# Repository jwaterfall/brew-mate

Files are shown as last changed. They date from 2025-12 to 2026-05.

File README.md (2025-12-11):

# BrewMate

BrewMate is my personal take on a compact coffee scale, derived from [WeighMyBru](https://github.com/031devstudios/weighmybru2). This isn't meant to be a replacement for WeighMyBru—it's just something I designed for myself to suit my preferences, and I'm sharing it in case anyone else wants it too.

Even though the 3D models and code for BrewMate were written from scratch, the project is fundamentally derived from WeighMyBru. I wanted to make the scale more compact and redesign both the scale and web user interfaces to fit my preferences.

BrewMate features a compact form factor of 80×80×18mm. I'm redesigning the scale UI to have a more informative main screen with battery status, Bluetooth, and WiFi status indicators. The project also includes extra hardware modifications to support battery charging detection (VBUS voltage detection using a voltage divider) and battery disconnect detection (3rd switch pin).

## Software Status

⚠️ **Important**: The BrewMate software is currently a work in progress (WIP) and is not ready for use. However, the compact case and alternative hardware can be used with the [WeighMyBru software](https://github.com/031devstudios/weighmybru2).

## Hardware

- ESP32-based microcontroller
  - XIAO ESP32C6
- HX711 load cell amplifier
- SSD1306 OLED display (128x32)
- TTP223 touch sensors
- 500g load cell
- 3.7V 1000mAh battery

## Hardware Differences from WeighMyBru

To fit my more compact case design, some component modifications are needed compared to the standard WeighMyBru BOM. The following table details the components that fit in this compact case:

| Component | Differences | Image |
| --- | --- | --- |
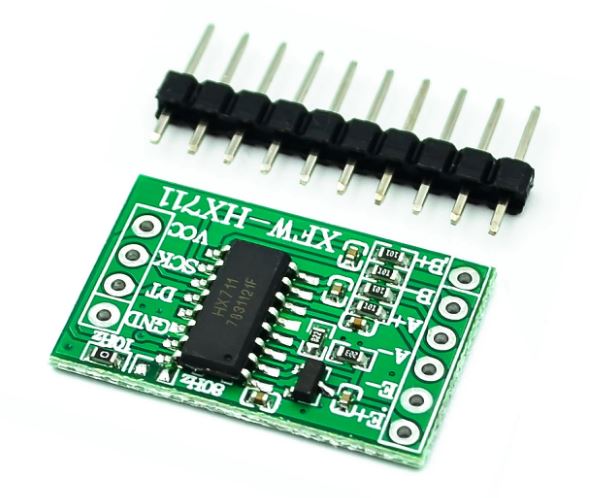
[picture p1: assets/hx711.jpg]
HX711 Compact
| **HX711 Load Cell Amplifier** | Uses the compact version without screw holes (instead of the large version with screw holes). Required to fit within the smaller enclosure. |  |
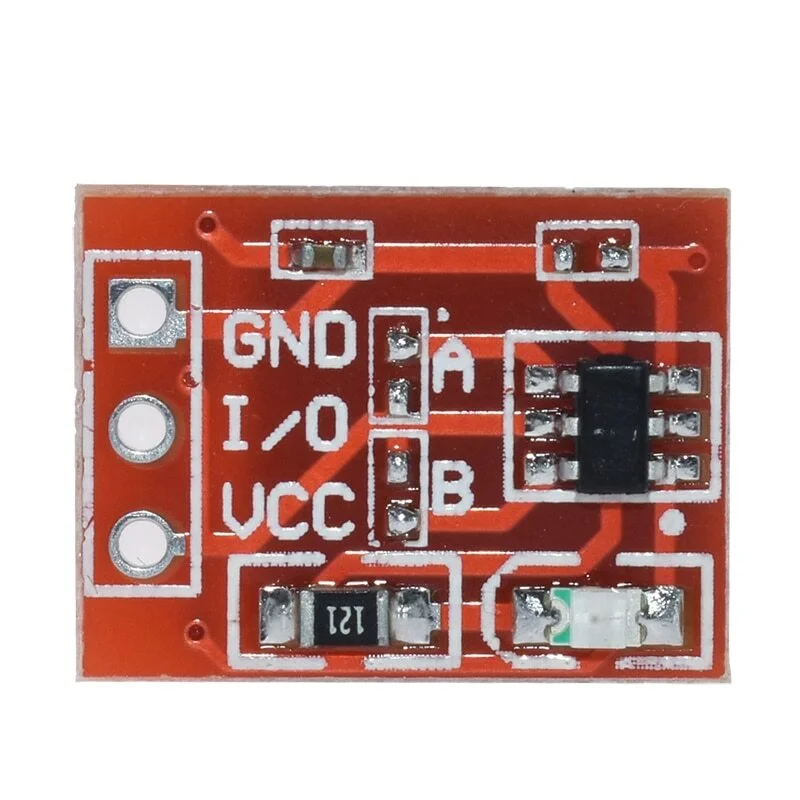
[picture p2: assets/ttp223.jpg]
TTP223 Compact
| **TTP223 Touch Sensors** | Uses compact version with red PCB (instead of standard size). Necessary for the reduced space. |  |
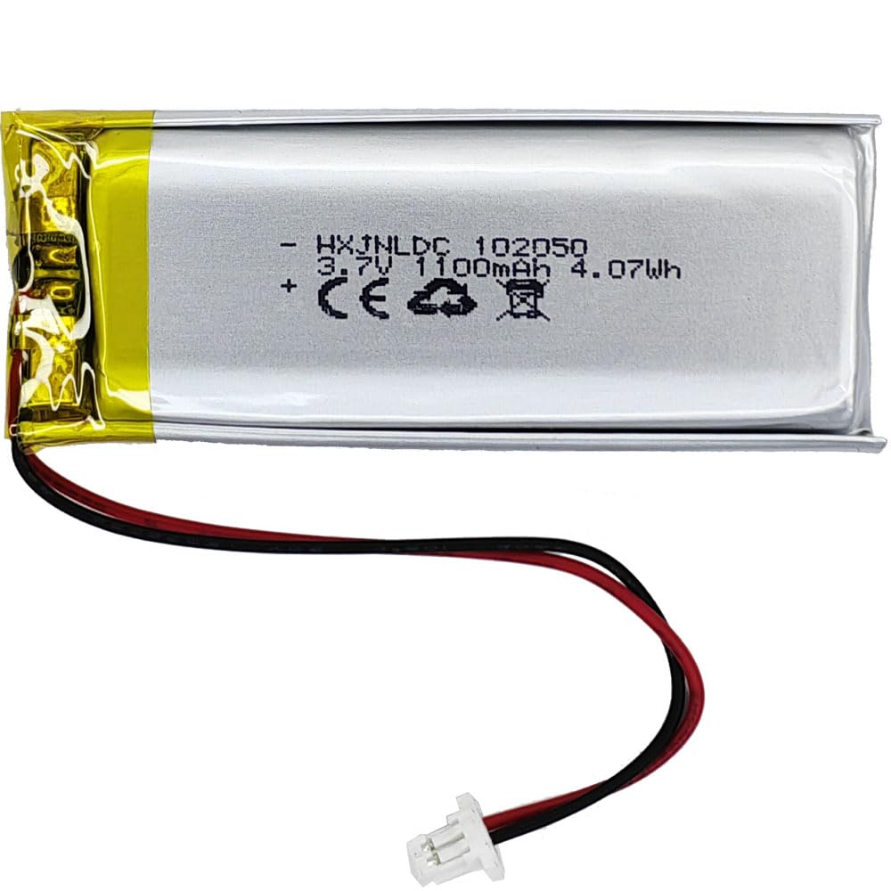
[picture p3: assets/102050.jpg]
102050 Battery
| **Battery** | Uses 102050 battery (10mm × 20mm × 50mm) instead of various sizes. Battery sizing is less forgiving due to the small enclosure. |  |
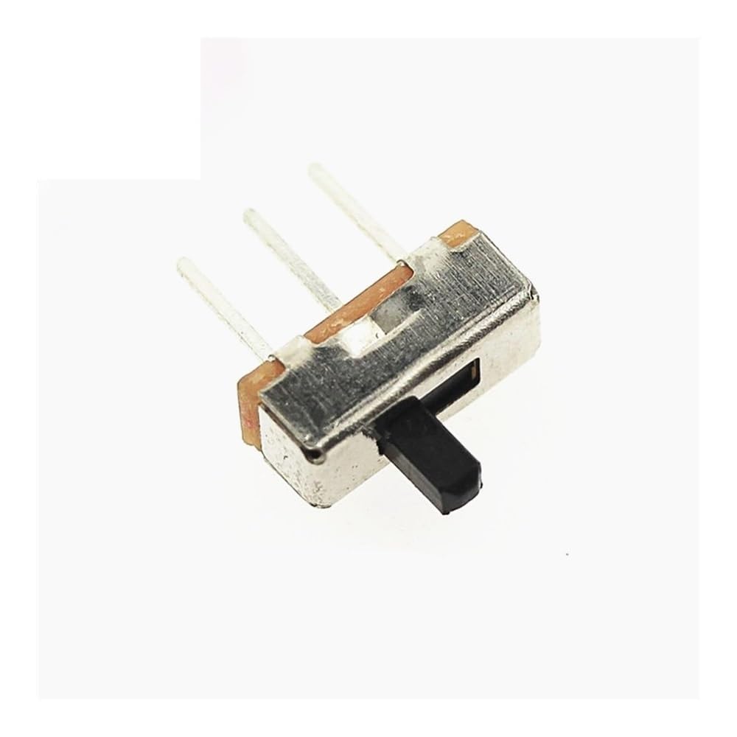
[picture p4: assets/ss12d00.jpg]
Switch
| **Switch** | Uses 4mm stem switch (optional, instead of 5mm stem). A 5mm switch will work but will stick out further and can be cut to length if needed. |  |
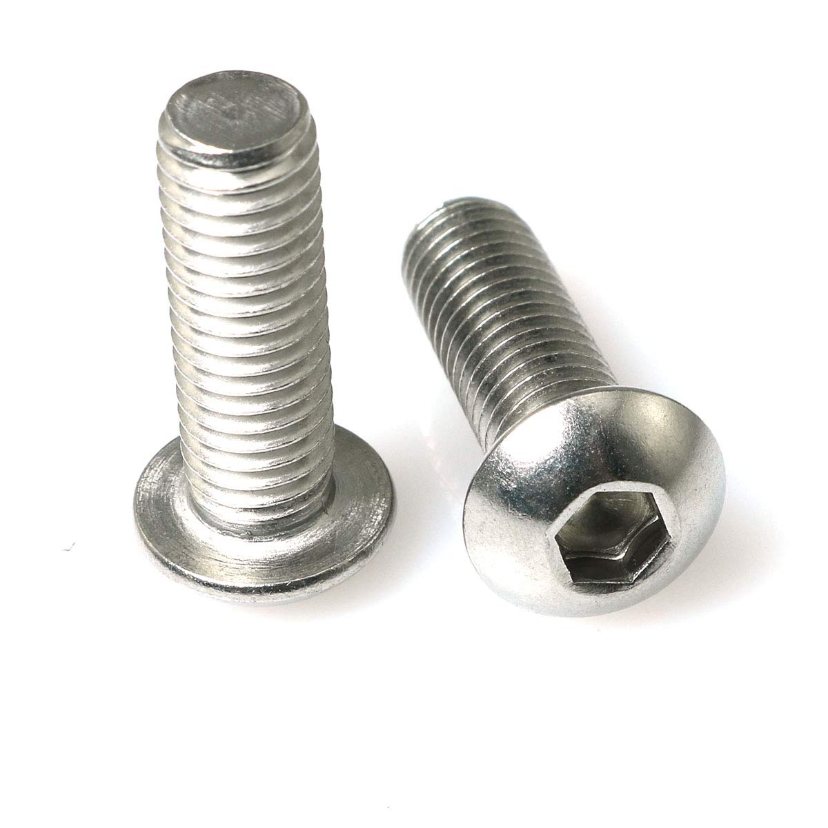
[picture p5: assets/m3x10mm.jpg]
Load Cell Screws
| **Load Cell Screws** | Uses 4× M3x10mm button head screws (instead of M3x12mm). Required for the more compact case design. |  |

## Features

- Flow rate calculation
- Battery level monitoring with USB charging detection
- Compact form factor
- WiFi Access Point mode for initial setup
- WiFi client mode to connect to your home network
- Web-based user interface
- Real-time weight and battery status via web API

## WiFi Web Interface

The scale includes a WiFi Access Point mode for initial setup. When powered on, the scale creates a WiFi network named "BrewMate" (password: `brewmate123`) that allows you to configure the device and connect it to your home WiFi network.

### Setup

1. **Build the web UI:**

   ```bash
   cd web
   pnpm install
   pnpm build
   ```

2. **Upload web files to LittleFS:**

   ```bash
   pio run -t uploadfs
   ```

3. **Upload the firmware:**

   ```bash
   pio run -t upload
   ```

4. **Initial Setup:**

   - Connect your device to the "BrewMate" WiFi network
   - Open a browser and navigate to `http://192.168.4.1`
   - Configure the scale to connect to your home WiFi network
   - Once connected, the scale will switch to WiFi client mode and can be accessed via your local network

5. **Using the scale:**
   - After initial setup, access the web interface via your local network
   - The web interface displays real-time weight, battery status, and allows you to tare the scale

### API Endpoints

- `GET /api/status` - Returns current scale status (weight, battery percentage, voltage, USB connection status)
- `POST /api/tare` - Tares the scale

The display will show a WiFi AP icon when the access point is active (during initial setup). Once connected to your WiFi network, the device operates in client mode.

## Credits

This project is derived from the [WeighMyBru](https://github.com/031devstudios/weighmybru2) project. While the 3D models and code for BrewMate were written from scratch, the project builds upon the WeighMyBru foundation. Thanks to the WeighMyBru project for the inspiration and foundation!

## License

This project is licensed under [CC BY-NC-SA 4.0](https://creativecommons.org/licenses/by-nc-sa/4.0/) (Creative Commons Attribution-NonCommercial-ShareAlike 4.0 International).

This means:

- **Attribution**: You must give appropriate credit
- **NonCommercial**: You may not use this work for commercial purposes
- **ShareAlike**: If you remix, transform, or build upon the material, you must distribute your contributions under the same license

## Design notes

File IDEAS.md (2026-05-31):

# BrewMate — Feature Ideas

A running list of potential features and improvements to keep track of for BrewMate.
These are candidate ideas, not a committed roadmap or a priority order — somewhere to
park things worth considering.

## Bluetooth (BLE)

- **Timer control over BLE** — handle start/stop/reset commands (e.g. Bean Conqueror
  command bytes) so a connected app can drive the brew timer, with confirmation packets
  sent back.
- **Accept GaggiMate-originated commands** (product ID `0x02`) in addition to the existing
  protocol, so GaggiMate command messages are honoured rather than ignored.
- **BLE connection-info summary** — expose connected/advertising state, RSSI, a
  human-readable signal-quality bucket, and the connection handle for the web UI / diagnostics.
- **Init robustness** — free-heap guard before starting BLE, release Classic-BT memory,
  wrap init so the scale keeps running if BLE fails, and tune TX power explicitly.

## Web UI & HTTP API

- **On-device load-cell calibration** — a guided flow (tare → place a known weight →
  calibrate) plus endpoints to read/set the calibration factor and report raw scale status.
  There's currently no way to calibrate the load cell from the device or UI.
- **Live flow-rate chart** and a session/average flow readout.
- **Brew timer controls** in the web UI (start / stop / reset).
- **WiFi management UI** — scan for networks, turn WiFi off to save power, clear stored
  credentials.
- **Display & filter settings** — configurable decimal places, and brewing-detection /
  stability / sample-count tuning.
- **Device & firmware info** — version, board, build date, chip, free heap; optionally an
  updates/info page.
- **Fast/minimal weight endpoints** for third-party integrations (low-latency weight + flow JSON).
- **Richer home-screen status** — Bluetooth, WiFi-signal, and scale-connected indicators
  alongside the battery.
- **Factory-reset endpoint** — clear stored settings and restart.

## Scale, flow rate & filtering

- **On-device calibration routine** (see Web UI above).
- **Adaptive filtering** — average filter when stable, median filter while brewing, with a
  transition/hysteresis phase and a fast-path that snaps to large weight changes instantly.
- **Auto-select the brewing threshold** from the calibration-factor magnitude (different
  load-cell sizes).
- **Flow-rate refinements** — reject tare transitions so taring doesn't spike the reading,
  fast-zero on weight removal, pause/resume around a tare, and a per-shot average flow tied
  to the timer.
- **HX711 presence detection** — detect a missing/disconnected load cell and degrade
  gracefully / report status.
- **Multi-sample tare** (average several reads) and NaN/not-ready guards on reads.

## Display & touch

- **Additional screens** — a status page (battery, HX711, BT, WiFi + IP) and transient
  message screens (taring, tared, sleeping, countdowns, WiFi on/off, low battery) with
  auto-timeout.
- **Richer main layout** — larger weight, stacked timer + flow rows.
- **Brightness / contrast control.**
- **Critical-battery flashing indicator.**
- **More touch gestures** — medium-hold and long-hold actions on the pads (e.g. status page,
  WiFi toggle, sleep) alongside the current short-press / hold behaviours.

## Power management & sleep

- **Deep sleep with wake-on-touch** — an on-screen countdown and touch-to-cancel before
  sleeping; wake when the touch pad is pressed.
- **Low-battery boot guard** — show a warning and sleep instead of running when the battery
  is critically low at boot.
- **CPU underclocking** for power saving.
- **Battery status strings** (Full / Good / Fair / Low / Critical) and low/critical flags
  driving warnings.

## WiFi & networking

- **mDNS / hostname** (e.g. `brewmate.local`).
- **Network scanning.**
- **Runtime reconnection & AP-fallback maintenance** — detect dropped connections and retry,
  falling back to AP mode if needed (current connect happens once at startup).
- **Runtime WiFi enable/disable**, persisted across boots, for battery saving.
- **AP power optimisation** / per-board antenna & TX-power tuning.
- **Clear stored credentials.**

## System, firmware & persistence

- **Firmware version & build metadata** — version, board, build date — shown at boot and via
  the API.
- **Move persisted settings into NVS/Preferences** (calibration, filter params, display
  options, WiFi-enabled state), beyond the current WiFi + battery-calibration JSON.
- **Factory reset** — a boot-time gesture and/or API endpoint.
- **Headless degrade** — keep running (web / BLE available) if the display fails to
  initialise, rather than halting startup as it does today.

## Worth considering (not present today)

- **Runtime OTA firmware updates** — the partition layout already supports A/B images.
- **Software watchdog.**
- **Captive portal** for first-time WiFi setup.
- **Multiple saved WiFi networks.**

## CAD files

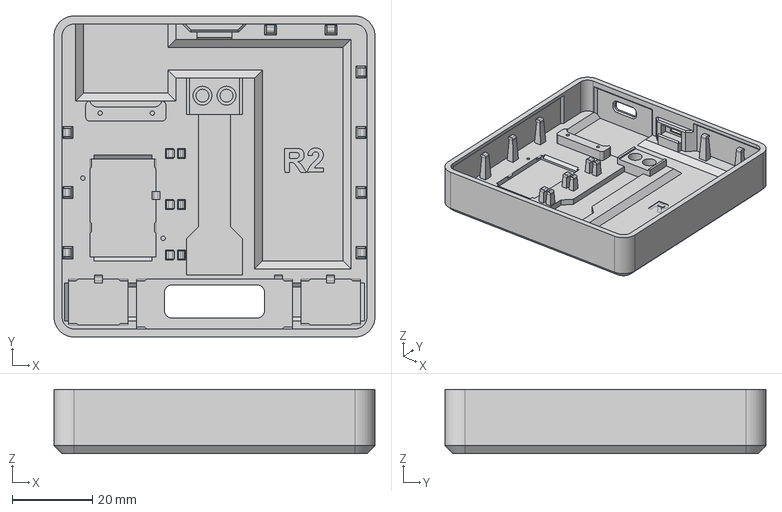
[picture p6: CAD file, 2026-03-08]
printed-parts/main.step
80.0 x 80.0 x 16.0 mm

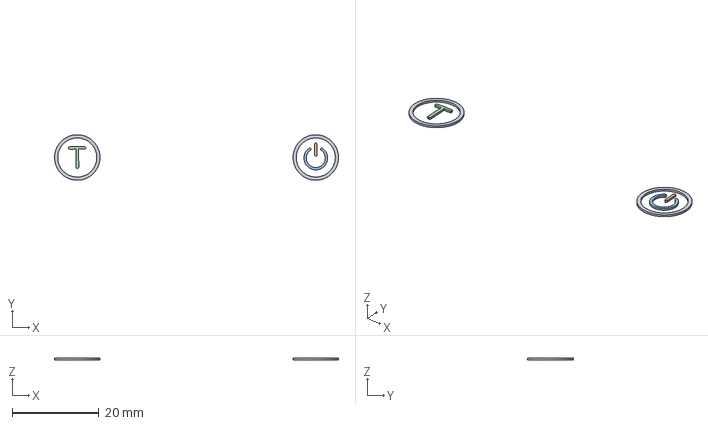
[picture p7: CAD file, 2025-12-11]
printed-parts/main_inlay.step
65.5 x 10.5 x 0.4 mm

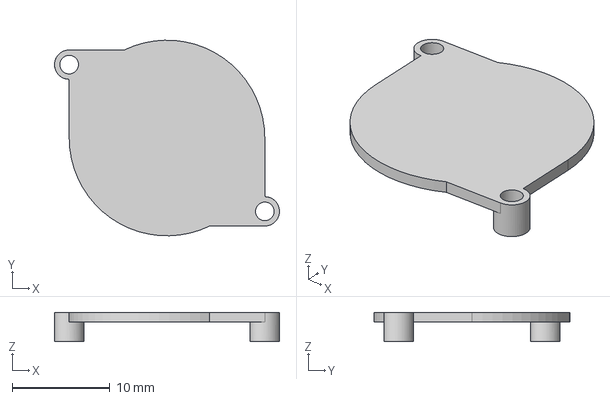
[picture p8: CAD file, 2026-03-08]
printed-parts/buzzer_mount.step
23.0 x 20.0 x 3.00 mm

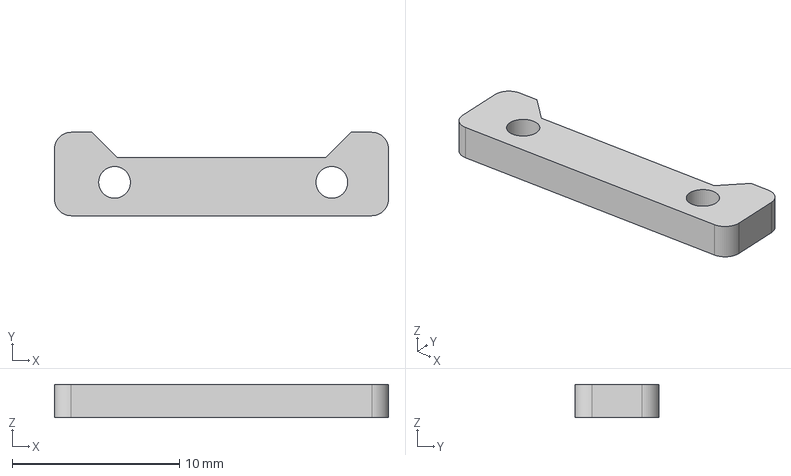
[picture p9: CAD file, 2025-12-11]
printed-parts/esp_clamp.step
20.0 x 5.00 x 2.00 mm

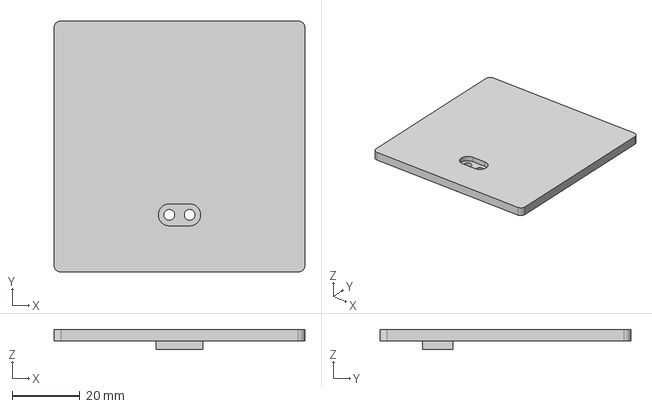
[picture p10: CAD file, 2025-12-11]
printed-parts/base.step
74.0 x 74.0 x 6.00 mm

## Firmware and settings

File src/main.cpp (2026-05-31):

#include <Arduino.h>
#include <LittleFS.h>
#include "logger.h"
#include "display.h"
#include "battery.h"
#include "scale.h"
#include "touch_sensor.h"
#include "buzzer.h"
#include "config_manager.h"
#include "device_state.h"
#include "scale_app.h"
#include "serial_protocol.h"
#include "wifi_manager.h"
#include "bluetooth_scale.h"

Display display;
Battery battery;
Scale scale;
TouchSensor touchSensor;
Buzzer buzzer;
ScaleApp app;
DeviceState deviceState;
WiFiManager wifiManager;
BluetoothScale bluetoothScale;

const unsigned long MIN_UPDATE_INTERVAL = 50;
unsigned long lastUpdate = 0;

// Dev "tap" proxy mode: entered automatically when the host dev server is
// talking to us, dropped when it goes quiet. The scale is a normal standalone
// device the rest of the time.
const char* HANDSHAKE = "BMTAP";
const unsigned long PROXY_TIMEOUT = 1500;
bool proxyMode = false;
unsigned long lastHostMs = 0;

RawInputs readRawInputs(unsigned long now) {
    // Non-blocking HX711 read: sample only when the chip has data ready,
    // otherwise reuse the last value, so the loop never stalls.
    static long lastRaw = 0;
    if (scale.isReady()) lastRaw = scale.readRaw();

    RawInputs in;
    in.nowMs = now;
    in.weightRaw = lastRaw;
    in.weightCalFactor = scale.getCalibrationFactor();
    in.batteryMv = battery.readBatteryMv();
    in.vbusMv = battery.readVbusMv();
    in.batteryCalFactor = battery.getCalibrationFactor();
    in.vbusCalFactor = battery.getVbusCalibrationFactor();
    in.batterySwitchRaw = battery.readSwitchRaw();
    in.tarePinRaw = touchSensor.readTareRaw();
    in.powerPinRaw = touchSensor.readPowerRaw();
    return in;
}

// Read host traffic: a handshake keepalive keeps us in proxy mode; framebuffer
// lines are blitted to the OLED while proxying.
void drainSerial(unsigned long now) {
    static char buf[1100];
    static size_t len = 0;
    static uint8_t frame[protocol::FRAME_BYTES];
    while (Serial.available()) {
        char c = Serial.read();
        if (c == '\n' || c == '\r') {
            if (len > 0) {
                buf[len] = '\0';
                if (strcmp(buf, HANDSHAKE) == 0) {
                    proxyMode = true;
                    lastHostMs = now;
                } else if (buf[0] == 'F') {
                    bool buzz;
                    if (protocol::decodeFrame(buf, frame, protocol::FRAME_BYTES, buzz)) {
                        proxyMode = true;
                        lastHostMs = now;
                        display.drawFrame(frame);
                        if (buzz) buzzer.playTouchSound();
                    }
                }
                len = 0;
            }
        } else if (len < sizeof(buf) - 1) {
            buf[len++] = c;
        }
    }
}

void setup() {
    // The host streams ~1 KB framebuffer lines; the default 256-byte USB-CDC RX
    // buffer would overflow and corrupt them. Enlarge it before begin().
    Serial.setRxBufferSize(4096);
    Serial.begin(115200);

    Logger::setLevel(LogLevel::Info);
    Logger::info("Starting scale project");

    if (!display.begin()) {
        Logger::error("Display initialization failed");
        return;
    }
    Logger::info("Display initialized");

    display.showBootScreen();

    buzzer.begin();
    Logger::info("Buzzer initialized");

    if (!scale.begin()) {
        Logger::error("Scale initialization failed");
    } else {
        Logger::info("Scale initialized");
    }

    DeviceConfig config = ConfigManager::load();
    battery.setCalibrationFactor(config.battery.batteryCalibrationFactor);
    battery.setVbusCalibrationFactor(config.battery.vbusCalibrationFactor);

    if (!wifiManager.begin()) {
        Logger::error("WiFi Manager initialization failed");
    } else {
        Logger::info("WiFi Manager initialized");
    }

    wifiManager.setBattery(&battery);
    wifiManager.setDeviceState(&deviceState);

    bluetoothScale.begin(&deviceState);
    bluetoothScale.onTare([]() {
        deviceState.requestTare();
    });
    Logger::info("Bluetooth initialized");
}

void loop() {
    unsigned long now = millis();

    wifiManager.update();
    bluetoothScale.update();
    drainSerial(now);

    if (proxyMode && now - lastHostMs > PROXY_TIMEOUT) {
        proxyMode = false;
    }

    if (now - lastUpdate >= MIN_UPDATE_INTERVAL) {
        lastUpdate = now;

        RawInputs in = readRawInputs(now);
        in.wifiConnected = wifiManager.isInitialized();
        in.wifiApMode = wifiManager.isApMode();
        in.bluetoothConnected = bluetoothScale.isConnected();
        in.immediateTare = deviceState.consumeTareRequest();

        String ip = wifiManager.isApMode() ? "192.168.4.1" : wifiManager.getConnectedIP().toString();
        strncpy(in.ipStr, ip.c_str(), sizeof(in.ipStr) - 1);
        in.ipStr[sizeof(in.ipStr) - 1] = '\0';

        // Always run the core so the web API / BLE weight stay live, even while
        // a host is driving the display in proxy mode.
        ScaleOutputs out = app.tick(in);
        deviceState.weight = out.weight;
        deviceState.batteryPercent = out.battery.percent;
        deviceState.batteryVoltage = out.battery.voltage;
        deviceState.usbConnected = out.battery.usb;
        deviceState.batteryDisconnected = out.battery.disconnected;

        if (proxyMode) {
            // Stream raw reads up; the host renders and sends frames back
            // (blitted in drainSerial).
            char line[200];
            protocol::encodeInputs(in, line, sizeof(line));
            Serial.println(line);
        } else {
            if (out.playBuzzer) buzzer.playTouchSound();
            display.showMainScreen(out.display);
        }
    }
}

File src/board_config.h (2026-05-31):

#pragma once

#ifdef BOARD_XIAO_ESP32C6
    #define SDA_PIN 20
    #define SCL_PIN 18
    #define BATTERY_PIN 0
    #define VBUS_PIN 2
    #define BATTERY_SWITCH_PIN 1
    #define HX711_DOUT 22
    #define HX711_SCK 23
    #define TARE_PIN 21
    #define POWER_PIN 19

#elif defined(BOARD_ESP32S3_SUPERMINI)
    #define SDA_PIN 8
    #define SCL_PIN 9
    #define BATTERY_PIN 7
    #define VBUS_PIN 10
    #define BATTERY_SWITCH_PIN 1
    #define HX711_DOUT 5
    #define HX711_SCK 6
    #define TARE_PIN 4
    #define POWER_PIN 3

#else
    #error "Unknown board. Please define BOARD_XIAO_ESP32C6 or BOARD_ESP32S3_SUPERMINI in platformio.ini"
#endif

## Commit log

2025-12-11 feat: added R1 printed parts, script to use littlefs on c6 and updated readme with hardware differences
    [base.step, esp_clamp.step, main.step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]
2025-12-11 feat: added m3 screws to readme hardware differences
2025-12-11 fix: added m3 screw image
2026-03-08 feat: current progress on bluetooth, timer, buzzer and frontend
    [buzzer_mount.step, main.step, partitions.csv]
2026-05-31 feat: host dev server with on-device proxy mode
    Extract all signal processing into a hardware-agnostic ScaleApp core
    (weight calibration/tare/smoothing, battery voltage->% curve, touch
    debounce/edge detection). The Scale/Battery/TouchSensor subsystems are
    now thin raw readers; processed values are cached back for the web API.
    Add a host dev server (scripts/dev_host.sh) that runs ScaleApp and renders
    the OLED on the laptop, streaming raw sensor reads up and the finished
    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
2026-05-31 docs: add feature-ideas backlog
    A running list of candidate features to track, separate from committed work.
2026-05-31 refactor: group firmware into core/drivers/net, add DeviceState
    Organise src/ by role: core/ (portable, no hardware deps -- scale_app,
    serial_protocol, display_render, device_state), drivers/ (thin hardware
    wrappers), net/ (connectivity + persistence), host/ (dev runner). Include
    paths are set in platformio.ini so headers are included by basename.
    Introduce DeviceState as the single source of processed values shared with
    the web API and BLE. Scale and Battery go back to pure raw readers -- the
    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
2026-05-31 feat: stabilize jumpy weight and battery readings
    Add display hysteresis so the on-screen weight and battery % hold steady
    under sensor noise and only move on a real change. The smoothed weight
    still feeds the web/BLE API for a responsive ramp; only the OLED uses the
    stabilized value. Hide the numeric battery % while charging, where charge
    current distorts the voltage and makes the reading unreliable.
    [display_render.h, main.cpp, scale_app.h]
